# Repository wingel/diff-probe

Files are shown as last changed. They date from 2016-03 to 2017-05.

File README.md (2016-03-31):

An almost GHZ active differential probe
=======================================

This is the design for an active differential probe which has a
bandwidth of about 800MHz and which is useful to beyond 1GHz.

I have written some articles about the probe:
[Part&nbsp;1](http://blog.weinigel.se/2016/02/26/ghz-differential-probe.html),
[Part&nbsp;2](http://blog.weinigel.se/2016/02/28/ghz-differential-probe-2.html), and
[Part&nbsp;3](http://blog.weinigel.se/2016/03/16/ghz-differential-probe-3.html).

A few notes
===========

So far I have only built the B variant of the probe, that is, the
probe with separate OP amps for the inputs.

On variant B, the input resistors R20/R21, R28/R29 and output
resistors R30/R31 are arranged in such a way that one can use just one
resistor between the input of the first resistor to the output of the
second resistor.  That's why it says "0Ω/NF" on one of the resistors
in both pairs.

The image in [S21ProbeBW_1.png](S21ProbeBW_1.png) shows a plot of the
frequency response for variant B using LMH6702 OP-AMPs, 150Ω on R20
and R28, 220Ω on R26, R27, R37 and R38 and 1.1k on R22 and R32.  Note
that the 150Ω resistors were mounted across R20/R21 and R28/R29 and
the and 50Ω matching resistor for the output was mounted across
R30/R31.  The power supply with a LMH6702 OP-AMPs should be about 5V
and the probe should be able to measure signals up to about +/-3.3V.

If you want the probe input to be AC coupled you can mount the input
resistor in its proper position on R20 and R28 and mount a capacitor
(0.1µF might be a good starting value) on R21 and R29.  You can also
AC couple the output by mounting the 50Ω matching resistor on R30 and
a another small capacitor on R31.

License
=======

[diff-probe](https://github.com/wingel/diff-probe) by
[Christer Weinigel](mailto:christer@weinigel.se) is licensed under a
[Creative Commons Attribution 4.0 International
License](http://creativecommons.org/licenses/by/4.0/).



The intent is to make this PCB available to anyone that finds it
useful as long as I get credit for the original design.  If you want
to use the design and have issues with the above license, please
contact me.

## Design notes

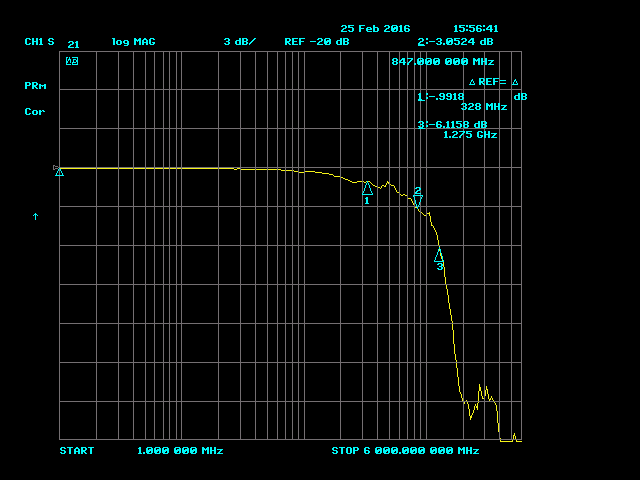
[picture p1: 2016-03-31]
S21ProbeBW_1.png

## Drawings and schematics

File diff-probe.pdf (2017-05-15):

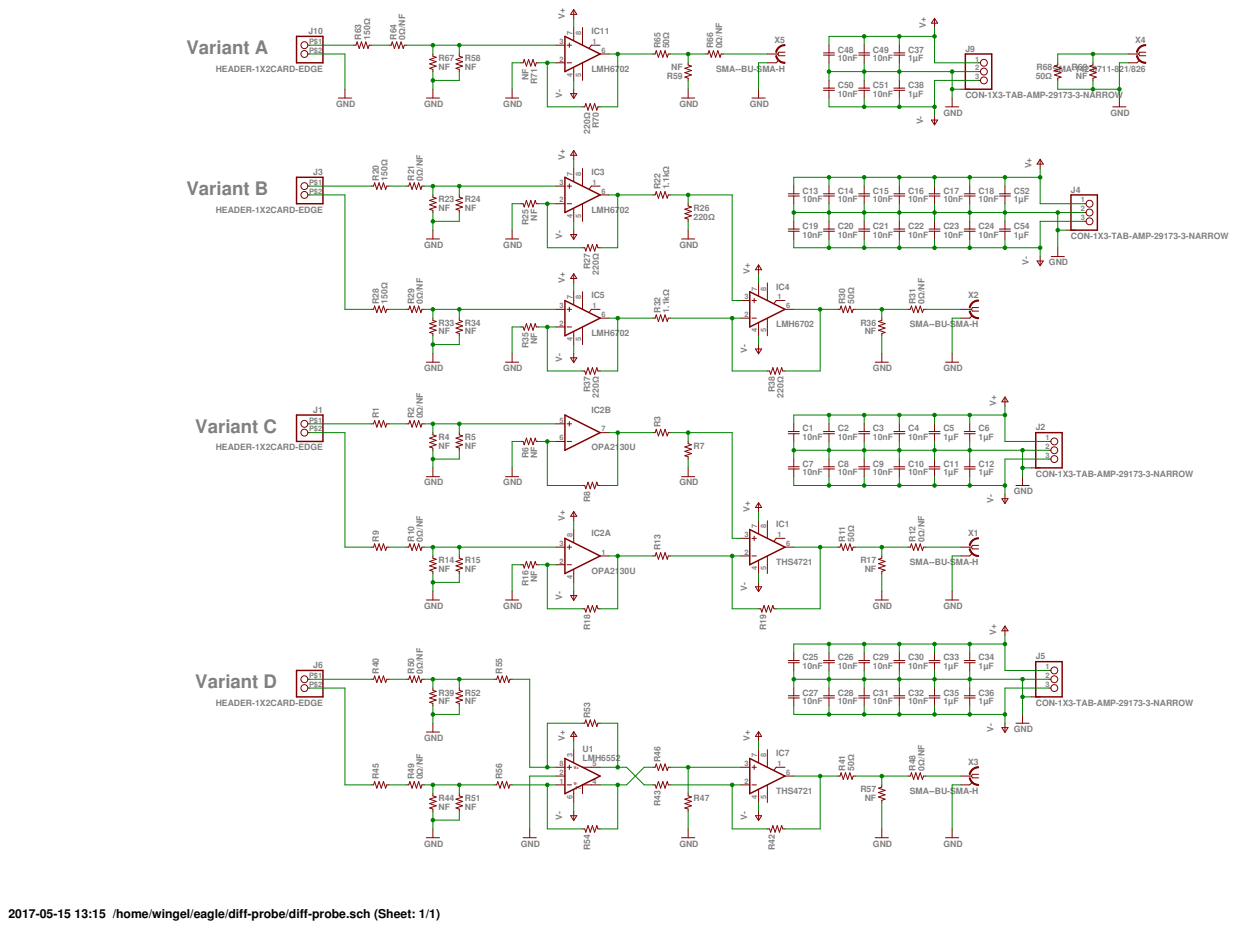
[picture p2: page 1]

0Ω/NF SMA--BU-SMA-H

2017-05-15 13:15 /home/wingel/eagle/diff-probe/diff-probe.sch (Sheet: 1/1)

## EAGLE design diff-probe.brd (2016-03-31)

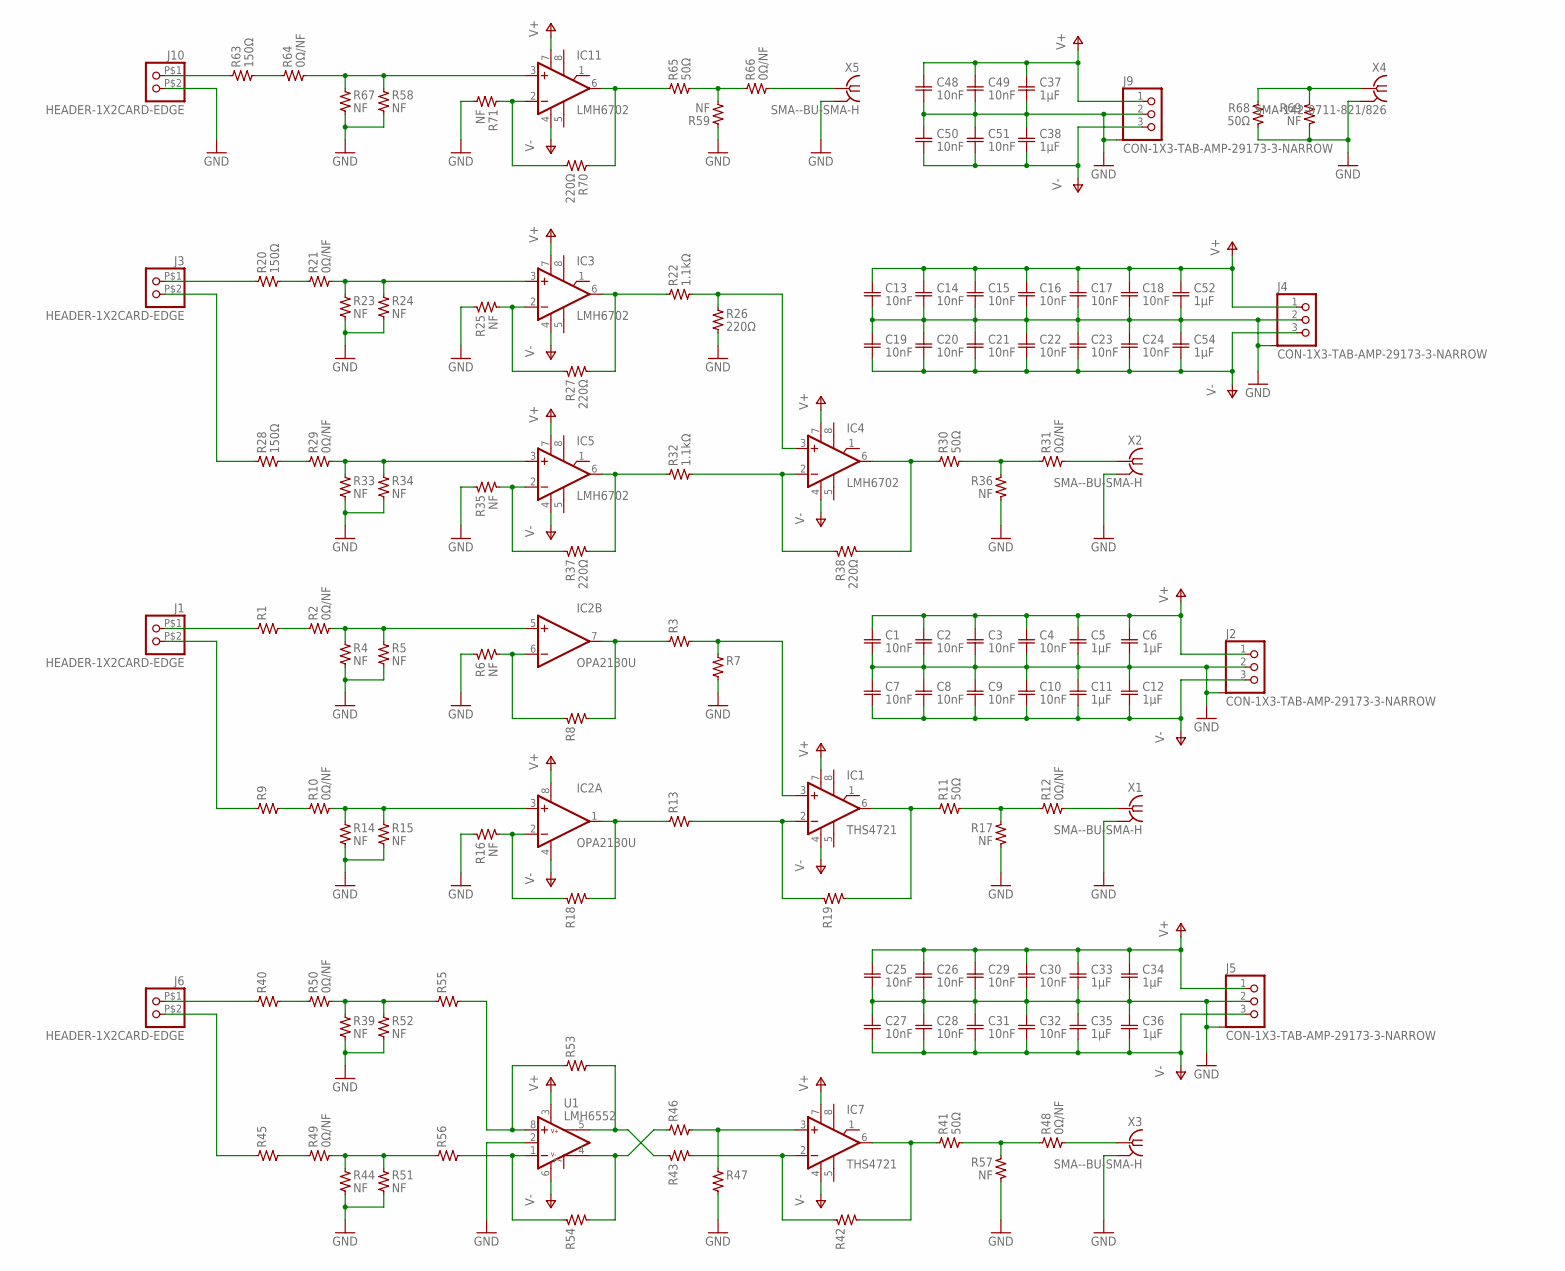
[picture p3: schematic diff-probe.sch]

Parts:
C1, C2, C3, C4, C7, C8, C9, C10, C13, C14, C15, C16, C17, C18, C19, C20, C21, C22, C23, C24, C25, C26, C27, C28, C29, C30, C31, C32, C48, C49, C50, C51: 10nF; 0402-SQUARE
C5, C6, C11, C12, C33, C34, C35, C36, C37, C38: 1µF; 0603-SQUARE
C52, C54: 1µF; 0603
IC1, IC7: THS4721; SO08
IC2: OPA2130U; SO08
IC3, IC4, IC5, IC11: LMH6702; SO08
J1, J3, J6, J10: HEADER-1X2CARD-EDGE; CARD_EDGE_PADS-1X2
J2, J4, J5, J9: CON-1X3-TAB-AMP-29173-3-NARROW; AMP-29173-3-NARROW
R1, R3, R7, R8, R9, R13, R18, R19, R40, R42, R43, R45, R46, R47, R53, R54, R55, R56: R-US-0402-SQUARE; 0402-SQUARE
R2, R10, R12, R21, R29, R31, R48, R49, R50, R64, R66: 0Ω/NF; 0402-SQUARE
R4, R5, R6, R14, R15, R16, R17, R23, R24, R25, R33, R34, R35, R36, R39, R44, R51, R52, R57, R58, R59, R67, R71: NF; 0402-SQUARE
R11, R30, R41, R65, R68: 50Ω; 0402-SQUARE
R20, R28, R63: 150Ω; 0402-SQUARE
R22, R32: 1.1kΩ; 0402-SQUARE
R26, R27, R37, R38, R70: 220Ω; 0402-SQUARE
R69: NF; 0603-SQUARE
U1: LMH6552; SO08
X1, X2, X3, X5: SMA--BU-SMA-H; BU-SMA-H
X4: SMA-142-0711-821/826; J502-ND-142-0711-821/826

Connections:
GND: C1.P$2 (2), C2.P$2 (2), C3.P$2 (2), C4.P$2 (2), C5.2, C6.2, C7.P$1 (1), C8.P$1 (1), C9.P$1 (1), C10.P$1 (1), C11.1, C12.1, C13.P$2 (2), C14.P$2 (2), C15.P$2 (2), C16.P$2 (2), C17.P$2 (2), C18.P$2 (2), C19.P$1 (1), C20.P$1 (1), C21.P$1 (1), C22.P$1 (1), C23.P$1 (1), C24.P$1 (1), C25.P$2 (2), C26.P$2 (2), C27.P$1 (1), C28.P$1 (1), C29.P$2 (2), C30.P$2 (2), C31.P$1 (1), C32.P$1 (1), C33.2, C34.2, C35.1, C36.1, C37.2, C38.1, C48.P$2 (2), C49.P$2 (2), C50.P$1 (1), C51.P$1 (1), C52.2, C54.1, J2.2, J2.P$4, J2.P$5, J4.2, J4.P$4, J4.P$5, J5.2, J5.P$4, J5.P$5, J9.2, J9.P$4, J9.P$5, J10.P$2 (2), R4.P$2 (2), R5.P$2 (2), R6.P$1 (1), R7.P$2 (2), R14.P$2 (2), R15.P$2 (2), R16.P$1 (1), R17.P$2 (2), R23.P$2 (2), R24.P$2 (2), R25.P$1 (1), R26.P$2 (2), R33.P$2 (2), R34.P$2 (2), R35.P$1 (1), R36.P$2 (2), R39.P$2 (2), R44.P$2 (2), R47.P$2 (2), R51.P$2 (2), R52.P$2 (2), R57.P$2 (2), R58.P$2 (2), R59.P$1 (1), R67.P$2 (2), R68.P$2 (2), R69.2, R71.P$2 (2), U1.2 (VCM), X1.2, X1.3 (2), X1.4 (2), X1.5 (2), X2.2, X2.3 (2), X2.4 (2), X2.5 (2), X3.2, X3.3 (2), X3.4 (2), X3.5 (2), X4.G@1 (2), X4.G@2 (2), X4.G@3 (2), X4.G@4 (2), X5.2, X5.3 (2), X5.4 (2), X5.5 (2)
unnamed: IC11.3 (+IN), R58.P$1 (1), R64.P$2 (2), R67.P$1 (1)
unnamed: R63.P$2 (2), R64.P$1 (1)
unnamed: J10.P$1 (1), R63.P$1 (1)
unnamed: R59.P$2 (2), R65.P$2 (2), R66.P$1 (1)
unnamed: IC11.6 (OUT), R65.P$1 (1), R70.P$1 (1)
unnamed: R66.P$2 (2), X5.1
unnamed: R53.P$1 (1), R55.P$2 (2), U1.8 (+IN)
unnamed: R40.P$2 (2), R50.P$1 (1)
unnamed: R43.P$1 (1), R53.P$2 (2), U1.5 (-OUT)
unnamed: R41.P$2 (2), R48.P$1 (1), R57.P$1 (1)
unnamed: IC7.6 (OUT), R41.P$1 (1), R42.P$2 (2)
unnamed: IC7.2 (-IN), R42.P$1 (1), R43.P$2 (2)
unnamed: R39.P$1 (1), R50.P$2 (2), R52.P$1 (1), R55.P$1 (1)
unnamed: R45.P$2 (2), R49.P$1 (1)
unnamed: R46.P$1 (1), R54.P$2 (2), U1.4 (+OUT)
unnamed: IC7.3 (+IN), R46.P$2 (2), R47.P$1 (1)
unnamed: J6.P$1 (1), R40.P$1 (1)
unnamed: J6.P$2 (2), R45.P$1 (1)
unnamed: R48.P$2 (2), X3.1
unnamed: R54.P$1 (1), R56.P$2 (2), U1.1 (-IN)
unnamed: R44.P$1 (1), R49.P$2 (2), R51.P$1 (1), R56.P$1 (1)
unnamed: IC11.2 (-IN), R70.P$2 (2), R71.P$1 (1)
unnamed: R68.P$1 (1), R69.1, X4.1
unnamed: IC2.5 (+IN), R2.P$2 (2), R4.P$1 (1), R5.P$1 (1)
unnamed: R1.P$2 (2), R2.P$1 (1)
unnamed: IC2.7 (OUT), R3.P$1 (1), R8.P$2 (2)
unnamed: IC3.3 (+IN), R21.P$2 (2), R23.P$1 (1), R24.P$1 (1)
unnamed: R20.P$2 (2), R21.P$1 (1)
unnamed: IC3.6 (OUT), R22.P$1 (1), R27.P$2 (2)
unnamed: R11.P$2 (2), R12.P$1 (1), R17.P$1 (1)
unnamed: R30.P$2 (2), R31.P$1 (1), R36.P$1 (1)
unnamed: IC4.6 (OUT), R30.P$1 (1), R38.P$2 (2)
unnamed: IC4.2 (-IN), R32.P$2 (2), R38.P$1 (1)
unnamed: IC5.3 (+IN), R29.P$2 (2), R33.P$1 (1), R34.P$1 (1)
unnamed: R28.P$2 (2), R29.P$1 (1)
unnamed: R12.P$2 (2), X1.1
unnamed: IC5.6 (OUT), R32.P$1 (1), R37.P$2 (2)
unnamed: IC4.3 (+IN), R22.P$2 (2), R26.P$1 (1)
unnamed: J3.P$1 (1), R20.P$1 (1)
unnamed: J3.P$2 (2), R28.P$1 (1)
unnamed: IC1.6 (OUT), R11.P$1 (1), R19.P$2 (2)
unnamed: IC1.2 (-IN), R13.P$2 (2), R19.P$1 (1)
unnamed: IC2.3 (+IN), R10.P$2 (2), R14.P$1 (1), R15.P$1 (1)
unnamed: R9.P$2 (2), R10.P$1 (1)
unnamed: IC2.1 (OUT), R13.P$1 (1), R18.P$2 (2)
unnamed: IC1.3 (+IN), R3.P$2 (2), R7.P$1 (1)
unnamed: J1.P$1 (1), R1.P$1 (1)
unnamed: J1.P$2 (2), R9.P$1 (1)
unnamed: IC2.2 (-IN), R16.P$2 (2), R18.P$1 (1)
unnamed: R31.P$2 (2), X2.1
unnamed: IC2.6 (-IN), R6.P$2 (2), R8.P$1 (1)
unnamed: IC5.2 (-IN), R35.P$2 (2), R37.P$1 (1)
unnamed: IC3.2 (-IN), R25.P$2 (2), R27.P$1 (1)
V+: C1.P$1 (1), C2.P$1 (1), C3.P$1 (1), C4.P$1 (1), C5.1, C6.1, C13.P$1 (1), C14.P$1 (1), C15.P$1 (1), C16.P$1 (1), C17.P$1 (1), C18.P$1 (1), C25.P$1 (1), C26.P$1 (1), C29.P$1 (1), C30.P$1 (1), C33.1, C34.1, C37.1, C48.P$1 (1), C49.P$1 (1), C52.1, IC1.7 (+VS1), IC2.8 (V+), IC3.7 (+VS1), IC4.7 (+VS1), IC5.7 (+VS1), IC7.7 (+VS1), IC11.7 (+VS1), J2.1, J4.1, J5.1, J9.1, U1.3 (V+)
V-: C7.P$2 (2), C8.P$2 (2), C9.P$2 (2), C10.P$2 (2), C11.2, C12.2, C19.P$2 (2), C20.P$2 (2), C21.P$2 (2), C22.P$2 (2), C23.P$2 (2), C24.P$2 (2), C27.P$2 (2), C28.P$2 (2), C31.P$2 (2), C32.P$2 (2), C35.2, C36.2, C38.2, C50.P$2 (2), C51.P$2 (2), C54.2, IC1.4 (-VS1), IC2.4 (V-), IC3.4 (-VS1), IC4.4 (-VS1), IC5.4 (-VS1), IC7.4 (-VS1), IC11.4 (-VS1), J2.3, J4.3, J5.3, J9.3, U1.6 (V-)

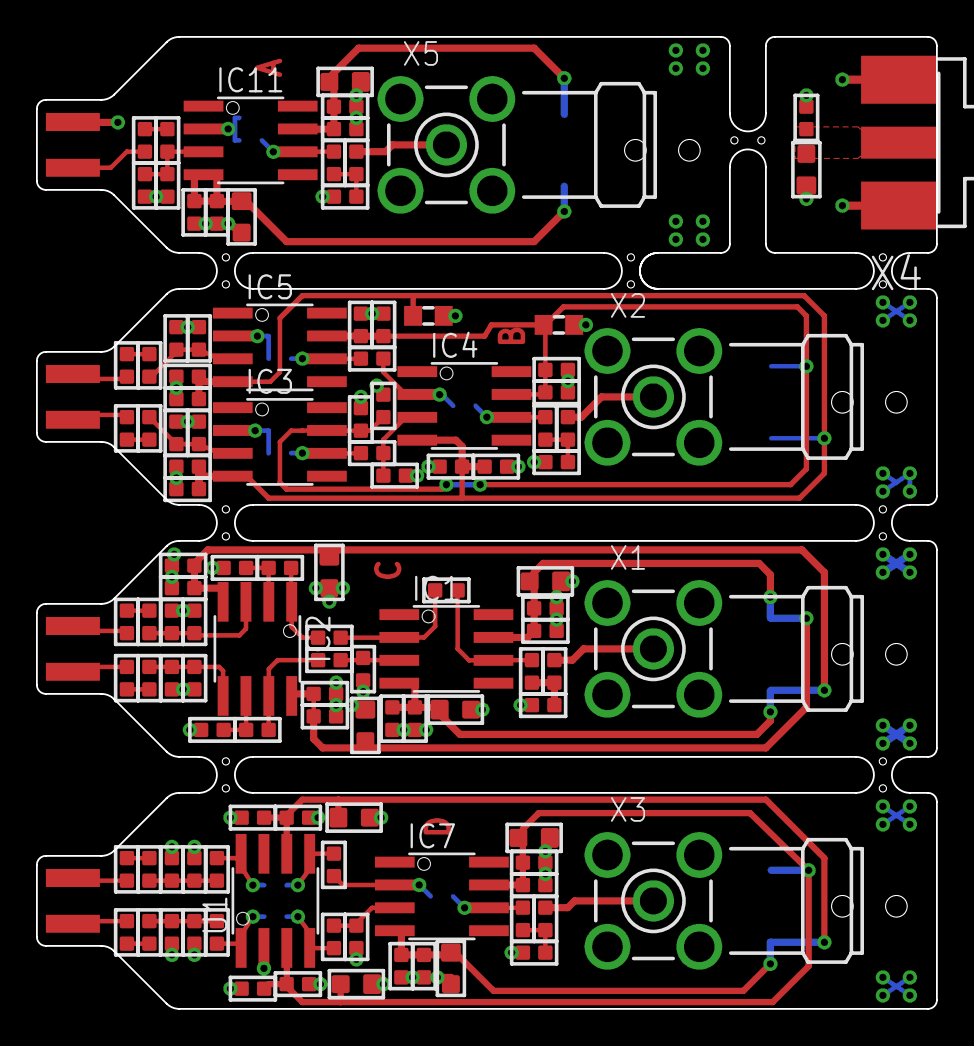
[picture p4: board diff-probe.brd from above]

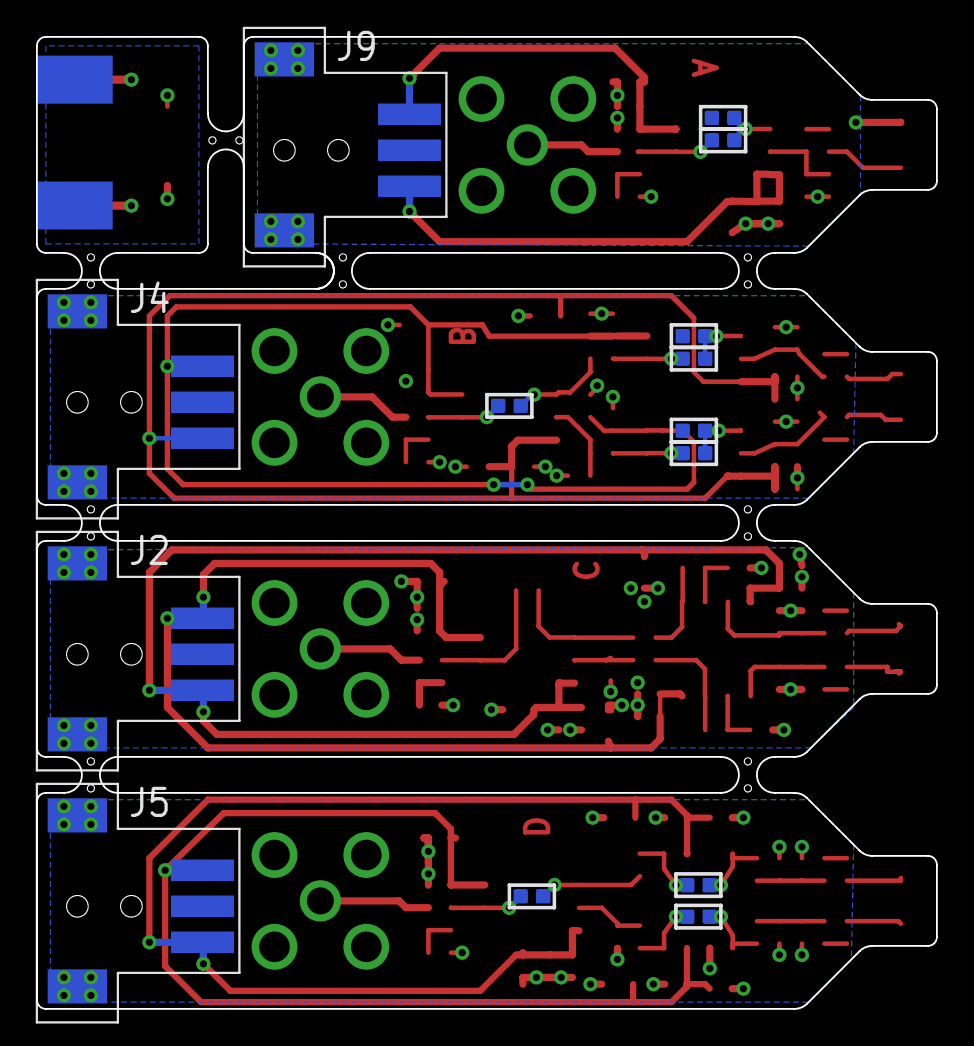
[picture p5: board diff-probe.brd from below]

Board: 2 copper layers, 50.0 x 54.0 mm, 133 parts (14 on the bottom side), 56 nets.

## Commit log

2016-03-31 Add eagle files for diff probe
    [diff-probe.brd, diff-probe.sch]
2016-03-31 Add plot of probe bandwith
2017-05-15 Add "Variant" text to schematics.
    [diff-probe.sch]
2017-05-15 Add PDF of schematics
